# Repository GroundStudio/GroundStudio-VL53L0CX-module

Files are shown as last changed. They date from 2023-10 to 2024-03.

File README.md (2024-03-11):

GroundStudio Time of Flight Distance Sensor module
====================================
TimeOfFlightModule REV0 0 1

Get it from [ardushop.ro](https://ardushop.ro/ro/home/2515-modul-vl53l0x-senzor-de-distanta-groundstudio.html)

Explore all the GroundStudio products at [GroundStudio.ro](https://groundstudio.ro/)

Description
-------------------
Time of Flight Distance Sensor module based on VL53L0CX sensor chip.

Contents
-------------------

* [/Documentation](https://github.com/GroundStudio/GroundStudio-VL53L0CX-module/tree/main/Documentation) -- Contains documentation written during creation of this repository, with readme.md index of its own!
* [/Firmware](https://github.com/GroundStudio/GroundStudio-VL53L0CX-module/tree/main/Firmware) -- Firmware (bootloaders, etc)
* [/Hardware](https://github.com/GroundStudio/GroundStudio-VL53L0CX-module/tree/main/Hardware) -- Schematics, layout.
* [/Libraries](https://github.com/GroundStudio/GroundStudio-VL53L0CX-module/tree/main/Libraries) -- Arduino/CircuitPython libraries. 
* [/Tools](https://github.com/GroundStudio/GroundStudio-VL53L0CX-module/tree/main) -- Tools needed for compiling, uploading bootloader, etc.

Versions
-------------------
*(Not all tags shown)*
* [V0.0.1] Initial version

License
-------------------

This is released under the [Attribution-ShareAlike 4.0 International (CC BY-SA 4.0)](https://creativecommons.org/licenses/by-sa/4.0/) license. 
**You are welcome to use this for commercial purposes.**

Please consider contributing back to this project or others to help the open-source hardware community continue to thrive and grow! 

Certifications:

[Open Source Hardware Association](https://certification.oshwa.org/ro000010.html)   
   
certification-mark-RO000010-wide (https://certification.oshwa.org/ro000010.html)

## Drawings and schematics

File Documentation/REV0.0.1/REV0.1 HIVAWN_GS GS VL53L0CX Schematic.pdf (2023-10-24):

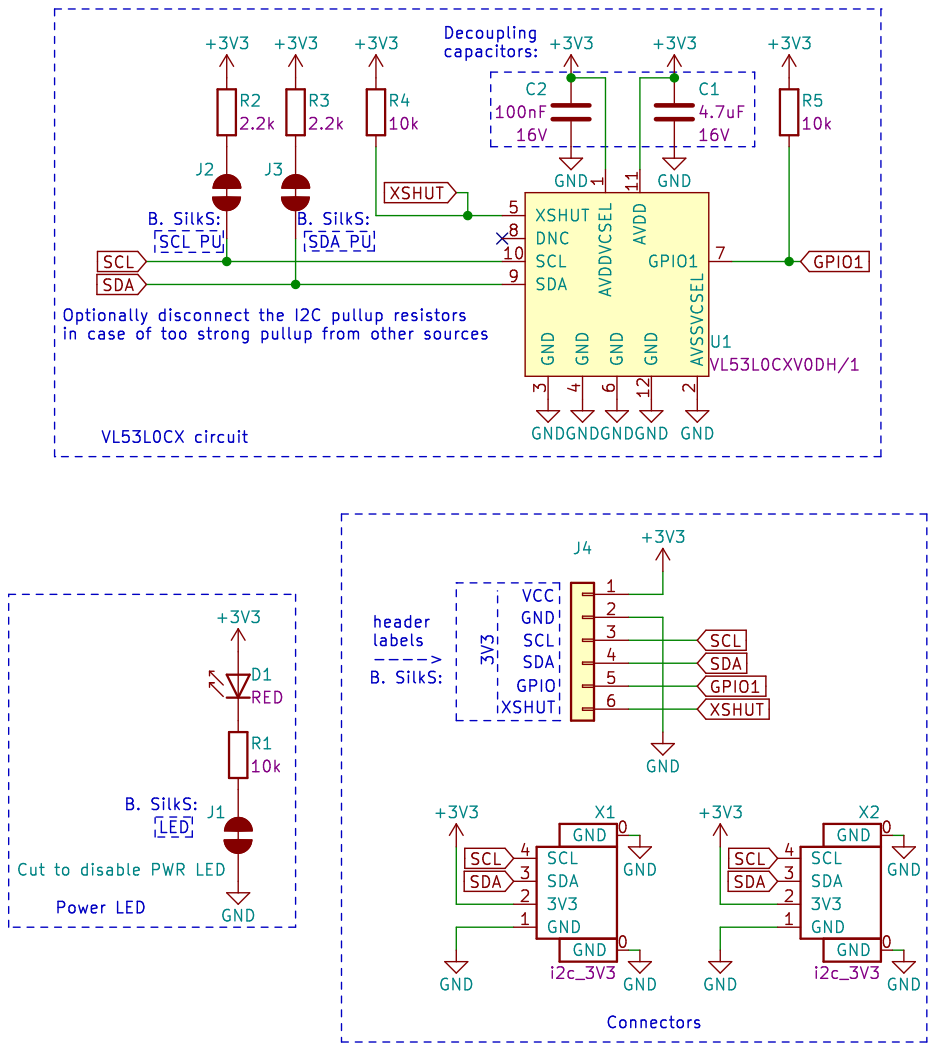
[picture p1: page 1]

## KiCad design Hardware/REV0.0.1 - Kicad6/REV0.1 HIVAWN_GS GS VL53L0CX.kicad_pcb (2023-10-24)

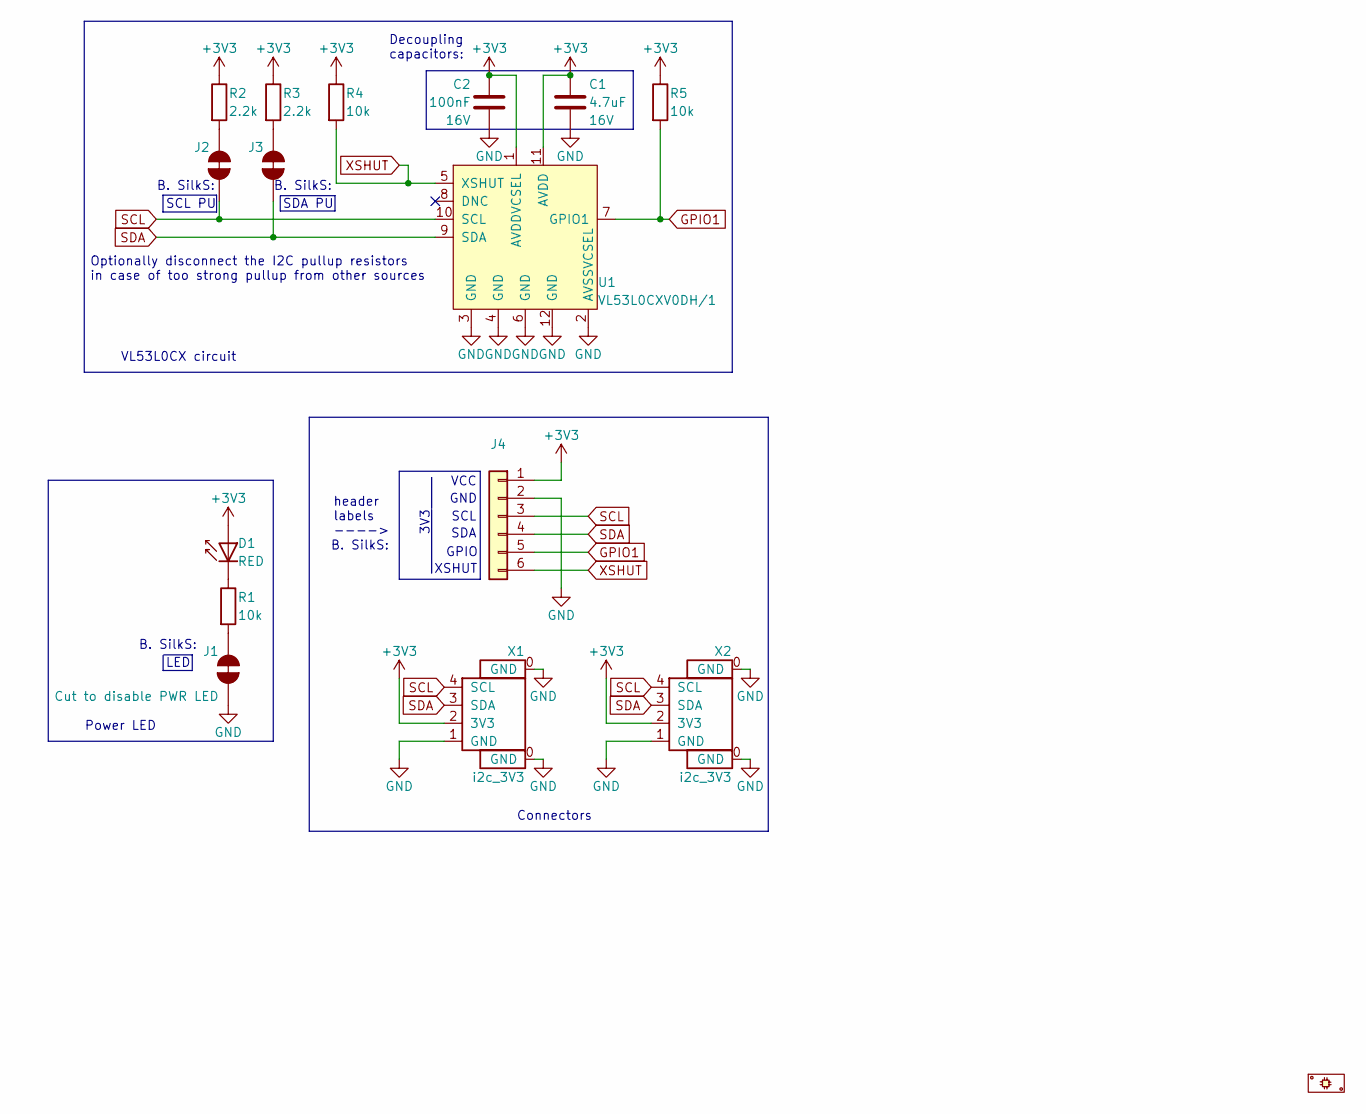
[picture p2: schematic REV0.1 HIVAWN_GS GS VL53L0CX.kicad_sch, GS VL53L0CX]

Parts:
C1: C_0402_4.7uF_16V; C_0402; Rated voltage 16V; MPN C0402X5R475M160NT; LCSC C729453
C2: C_0402_100nF_16V; C_0402; Rated voltage 16V; MPN 0402B104K160CT; LCSC C83056
D1: LED_0402_RED; LED_0402; MPN TZ-P2-0402RTIA1-0.45T; LCSC C779449
J1: Cut to disable PWR LED; SolderJumper_NC
J2, J3: SolderJumper_NC
J4: PinHeader_1x06_P2.54_V_M; PinHeader_1x06_P2.54mm_Vertical_Male; MPN C37208; LCSC C37208
P1: PCB; MPN HIVAWN_GS_PCB
R1, R4, R5: R_0402_10k; R_0402; MPN 0402WGJ0103TCE; LCSC C25531
R2, R3: R_0402_2.2k; R_0402; MPN RC-02W2201FT; LCSC C258093
U1: VL53L0CXV0DH/1; VL53L0CXV0DH_1; MPN VL53L0CXV0DH/1; Digi-Key_PN 497-16538-1-ND
X1, X2: SH_1x04_P1.0_H; SH__1x04_P1.00mm_Horizontal; MPN C145956; LCSC C145956

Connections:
+3V3: C1.1, C2.2, D1.2 (A), J4.1, R2.1, R3.1, R4.1, R5.1, U1.1 (AVDDVCSEL), U1.11 (AVDD), X1.2 (3V3), X2.2 (3V3)
GND: C1.2, C2.1, J1.1, J4.2, U1.2 (AVSSVCSEL), U1.3 (GND), U1.4 (GND), U1.6 (GND), U1.12 (GND), X1.0 (GND), X1.1 (GND), X2.0 (GND), X2.1 (GND)
GPIO1: J4.5, R5.2, U1.7 (GPIO1)
unnamed: D1.1 (K), R1.1
unnamed: J1.2, R1.2
unnamed: J2.2, R2.2
unnamed: J3.2, R3.2
SCL: J2.1, J4.3, U1.10 (SCL), X1.4 (SCL), X2.4 (SCL)
SDA: J3.1, J4.4, U1.9 (SDA), X1.3 (SDA), X2.3 (SDA)
XSHUT: J4.6, R4.2, U1.5 (XSHUT)

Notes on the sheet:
Power LED
XSHUT
B. SilkS:
Optionally disconnect the I2C pullup resistors in case of too strong pullup from other sources
header labels ---->
VL53L0CX circuit
SCL
GND
Connectors
SDA PU
LED
VCC
GPIO
Decoupling capacitors:
3V3
SCL PU
SDA

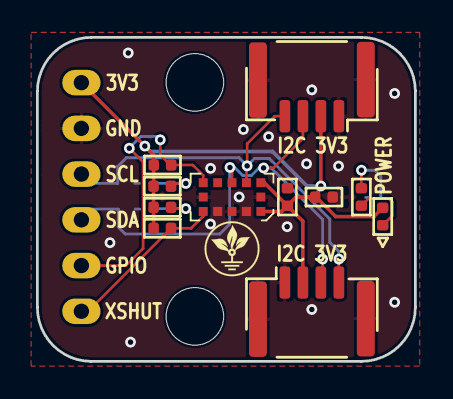
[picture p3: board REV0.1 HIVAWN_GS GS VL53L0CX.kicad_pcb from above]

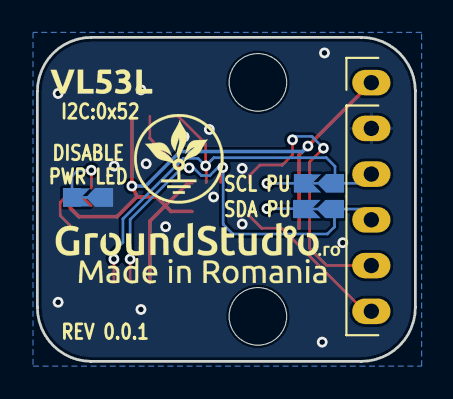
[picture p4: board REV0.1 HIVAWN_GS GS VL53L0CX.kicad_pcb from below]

Board: 2 copper layers, 21.0 x 18.0 mm, 15 parts (4 on the bottom side), 10 nets.

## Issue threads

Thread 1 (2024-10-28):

Jade Pebble + VL53L0X

alexandru-g, 2024-10-28:
Steps:
1. Connect Jade Pebble and VL53L0X using Stemma cable
2. Initialize VL53L0X using 0x52 address using CircuitPython

`ValueError: No I2C device at address: 0x52`

There are 6 sensors on the same I2C bus. PullUp resistors are enabled on sensors via jumpers,

alexandru-g, 2024-10-29:
I am now trying with only 1 sensor connected and it still can't find any I2C device at 0x52.

alexandru-g, 2024-10-29:
Found the issue. Guys, your sensor's address is the default VL53L0X 0x29, not 0x52 as you advertise it in the description and on ardushop.
